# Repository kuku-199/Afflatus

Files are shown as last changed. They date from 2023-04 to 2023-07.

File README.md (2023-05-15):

# Afflatus💡
           
* [**中文版本**](./README_zh.md)
## Afflatus STM32G4xx Open Development Board🚀
* This project used STM32G431 to master chip.A complete board to be made up of **Commaner**+**Expansion**
>`STM32G431CBU6` Core Board

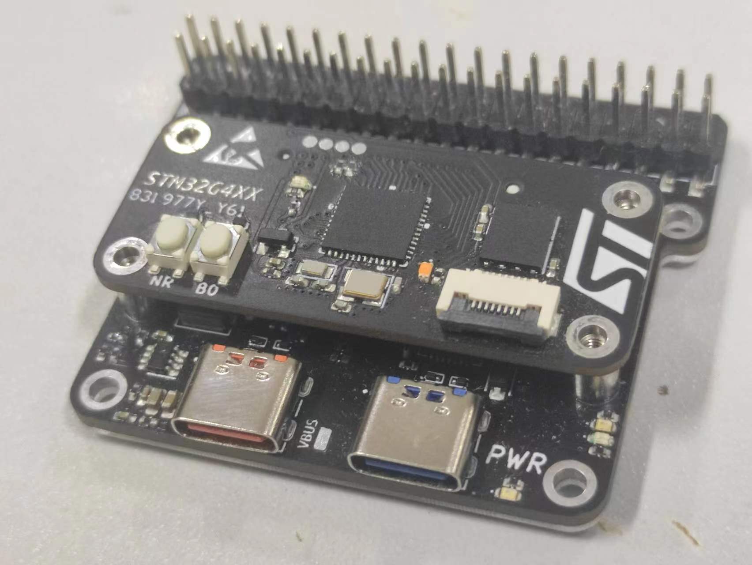
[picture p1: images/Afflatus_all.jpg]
"Afflatus_all"


## Commander✨📟

|Top|Bottom|
|:--:|:--:|
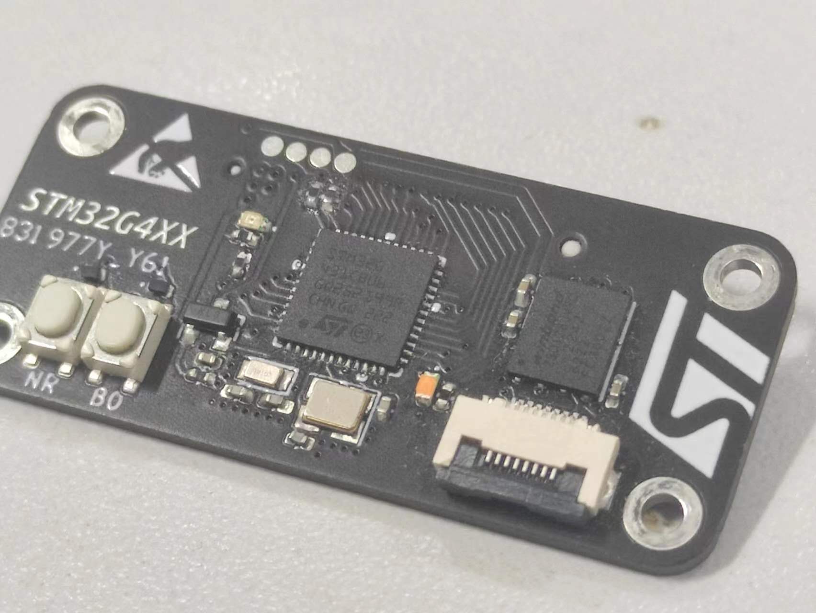
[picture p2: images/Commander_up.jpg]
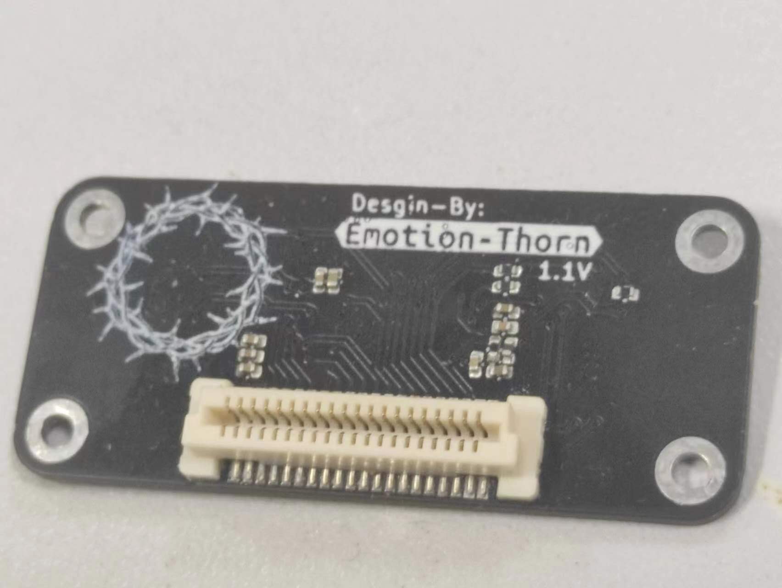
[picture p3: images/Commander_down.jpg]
"down"
||

>At present core boaed onboard Flash,LED,NRST and BOOT0 keys,Reserved serial interface of LDC,Need`0.8mm wire the connection`

>Commander have used `0.8mm`BTB_2x20P，`Not connected to Expansion`Download program can use reserved SW bonding pad to connected `Cable`or`Test probe`Download program

>Commander`none the LDO and DC-DC to buck`,to the extent that core board power only give`3.3V`❗ ❗ ❗

## Expansion🔌⚡🚀

|Top|Bottom|
|:--:|:--:|
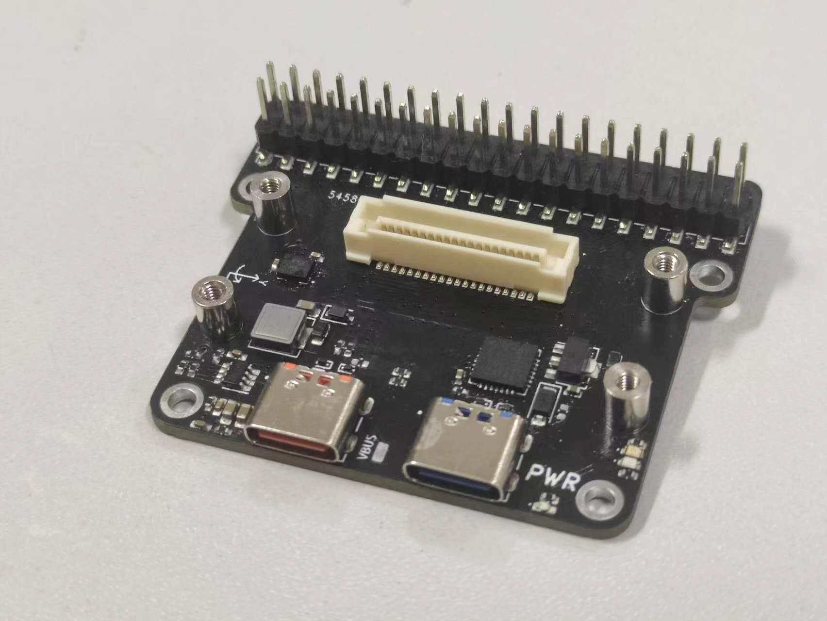
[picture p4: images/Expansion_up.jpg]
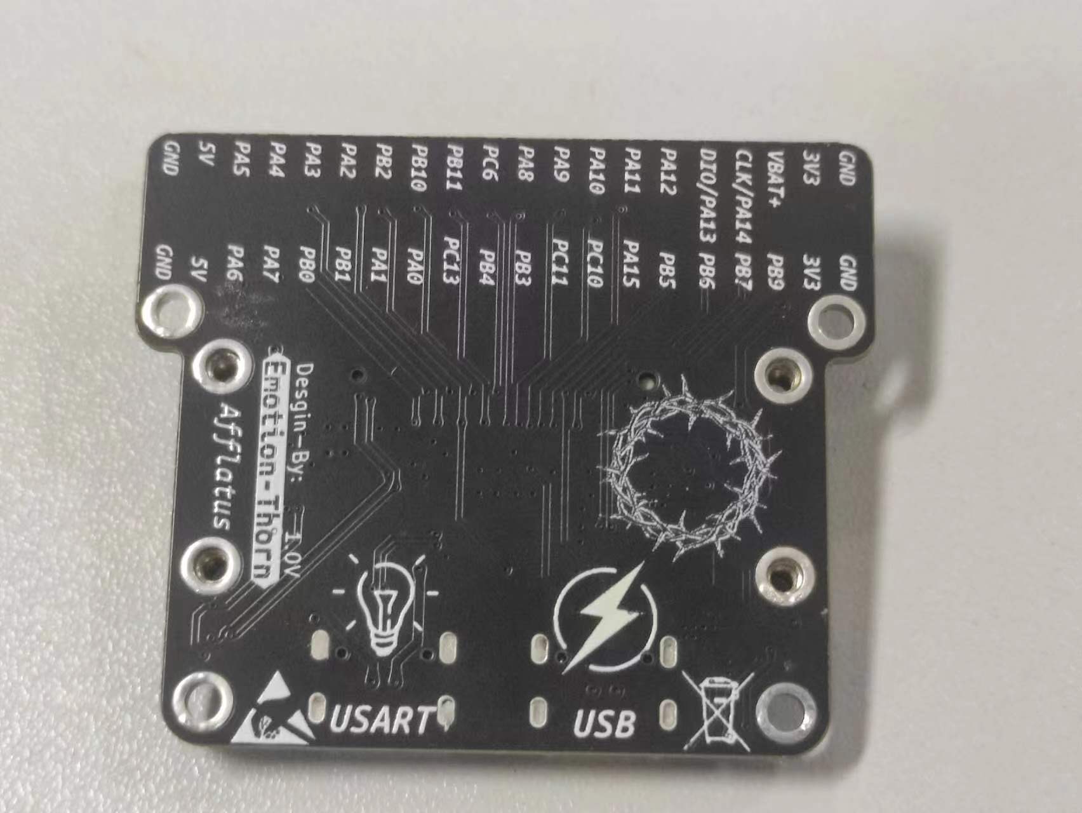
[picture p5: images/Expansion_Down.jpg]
"down"
||

* 1 USB support PD
* 1 USART to USB port
* 1 IMU(BMI270)
* 1 40P header 

>Expansion have one`CP2102`USB can be connected for serial communication.STM32G431CBU6 support `UCPD`so the USB plug support PD and have one DC-DC buck module⚡

>Consider that newbies may be less likely to use the STM32's built-in USB hardware controls,so i reserved USB_D+ pull-up R CC1,CC2 pull-down R`0402`bonding pad,it's recommended to weld pull-down R for CC1 and CC2🔌

>Expansion the type of embedded stud is`M2x4x5.0x2.5x1.0`,BTB combined height is`5.0mm`
I/O Pin header is 2.54mm`SMT`.Optionally add baseplate for Expansion,[**Baseplate file**](./HDK/Expansion/Choice.dxf)effect maps
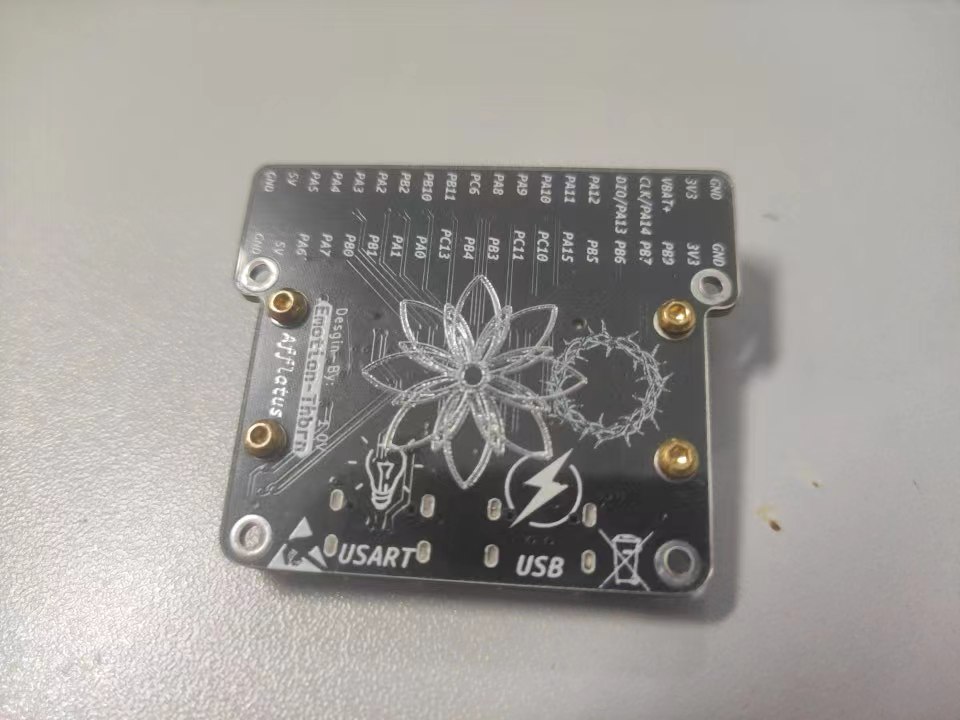
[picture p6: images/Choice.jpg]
"Choice"


## Important statement ❗ ❗ ❗

*  ⚠️Please read the PCB Engineering Instructions pdf file
    - 📖[Engineering declaration](./%E5%B7%A5%E7%A8%8B%E5%A3%B0%E6%98%8E.pdf)
* 👓The whole project uses a two-layer process. If you don't have kicad installed, you can directly view Bom for welding. Gerber files are also in HDK
    - [**Commander-bom**](htmlpreview.github.io/?./HDK/Commander/bom/Commander.html)
    - [**Expansion-bom**](./HDK/Expansion/bom/Expansion.html)
* Continuous update, currently replenishing Demo.📃
* welcome to submit your questions, and I also hope you can submit your own updates to the project📡
* I E-mail**2981263629@qq.com**,if you have questions or new idea can send an email to me⌨
* ❗ ❗ ❗ BUG of IO silk-screen in early stage versions,do not affect usage.(Partial left-right reverse).It has now been repaired.❗ ❗ ❗

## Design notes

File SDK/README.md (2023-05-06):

# Ongoing update📤
## Test file can test flash usart usb imu(bmi270) and led(Suggestion after created Download this program)🎫
## USB file have more example about developement of USB_Deviec.
* ## [**Detailed description(USB)**](./USB/README.md)👈
## Demo file have example for Afflatus DSP and help document
* ## [**Detailed description(Demo)**](./Demo/README.md)👈

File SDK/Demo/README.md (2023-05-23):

# About Demo 
## ADC NOTE:
> In ADC_Demo VBUS value may not be accurate.Becuase this value from resistance divider.In fact, it should be use float when you calculate it ,but this demo i use int.

>If you just put in USART ,there is also voltage in VBUS(about2.7v). 

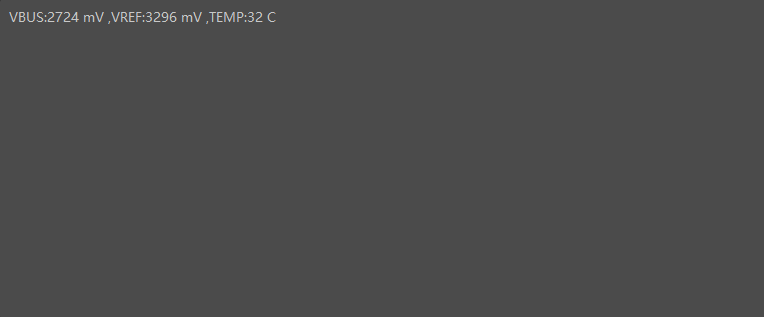
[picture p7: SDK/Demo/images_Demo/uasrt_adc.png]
"USART_ADC"
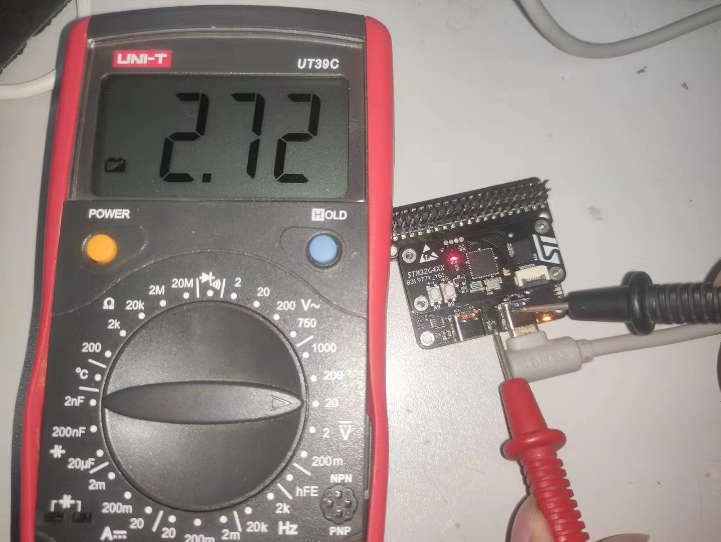
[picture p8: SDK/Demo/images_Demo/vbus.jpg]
"VBUS"
|
## WS2812 NOTE:
>In WS2812 Demo i used WS2812B.If you don't have a light strip, you can get the data in hdk

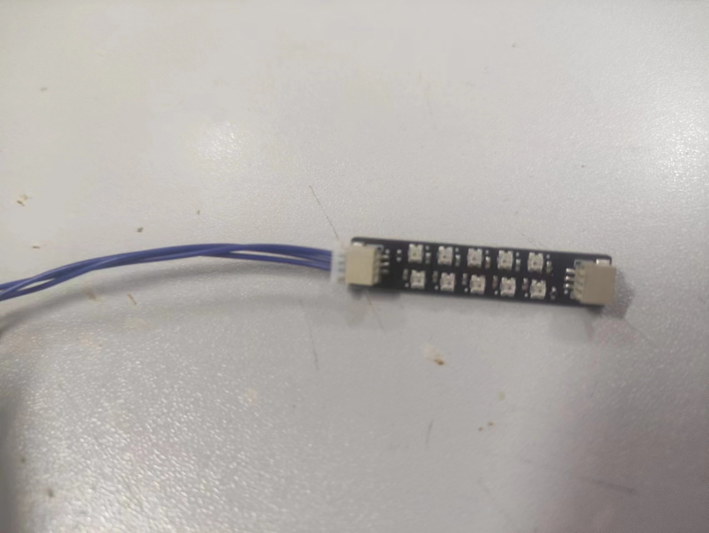
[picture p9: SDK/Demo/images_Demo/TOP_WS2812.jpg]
"TOP"
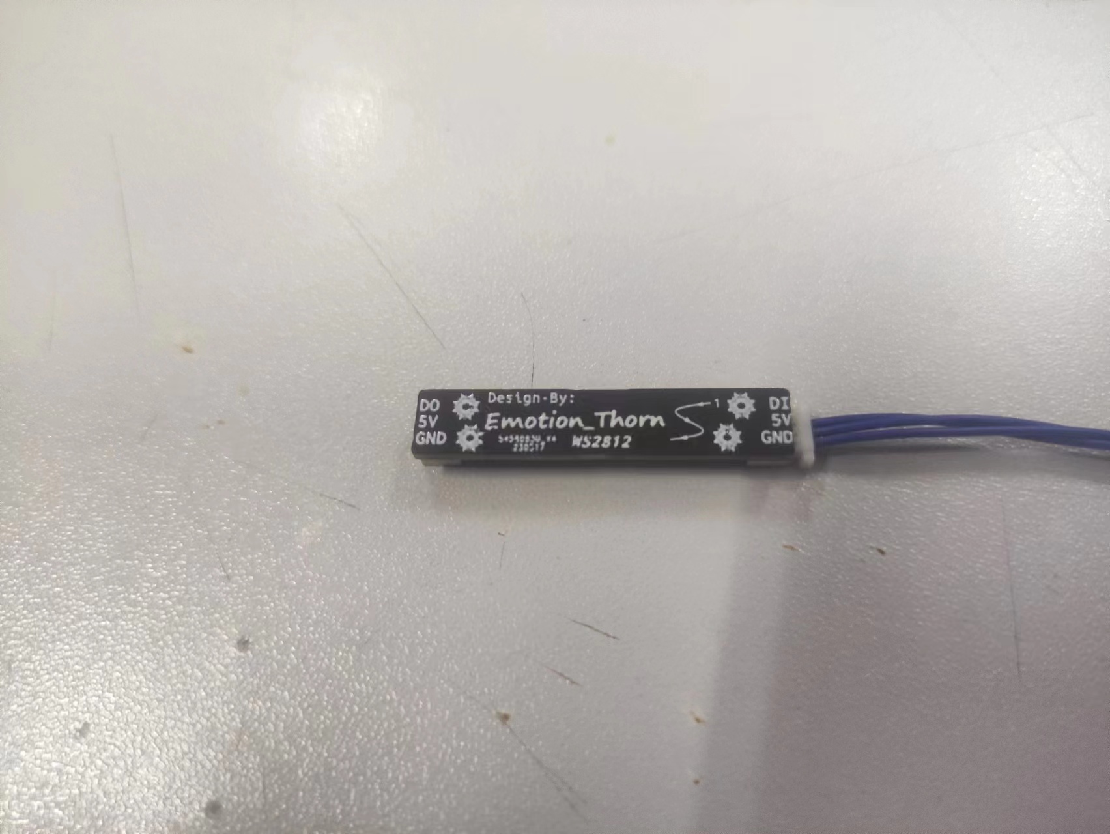
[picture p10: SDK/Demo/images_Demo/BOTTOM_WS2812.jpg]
"BOTTOM"
|
## In this File you use DSP of Afflatus API 
## Support Feature List👇
* Flash(W25Qxx)  [**Help Document**](./Doc/W25Qxx.pdf)👈
* ADC is used STM_HAL
* RGB(WS2812)[**Help Document**](./Doc/W25Qxx.pdf)👈

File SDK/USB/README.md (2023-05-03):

># USB_VPC
>* Download this program,In your SSCOM can see word "USB_VPC_Test"
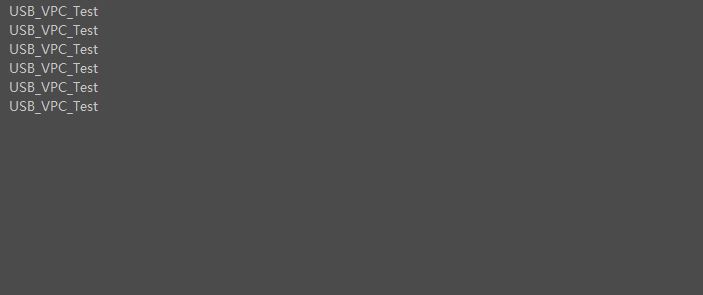
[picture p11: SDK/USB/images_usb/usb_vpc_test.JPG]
"photo_test_word"

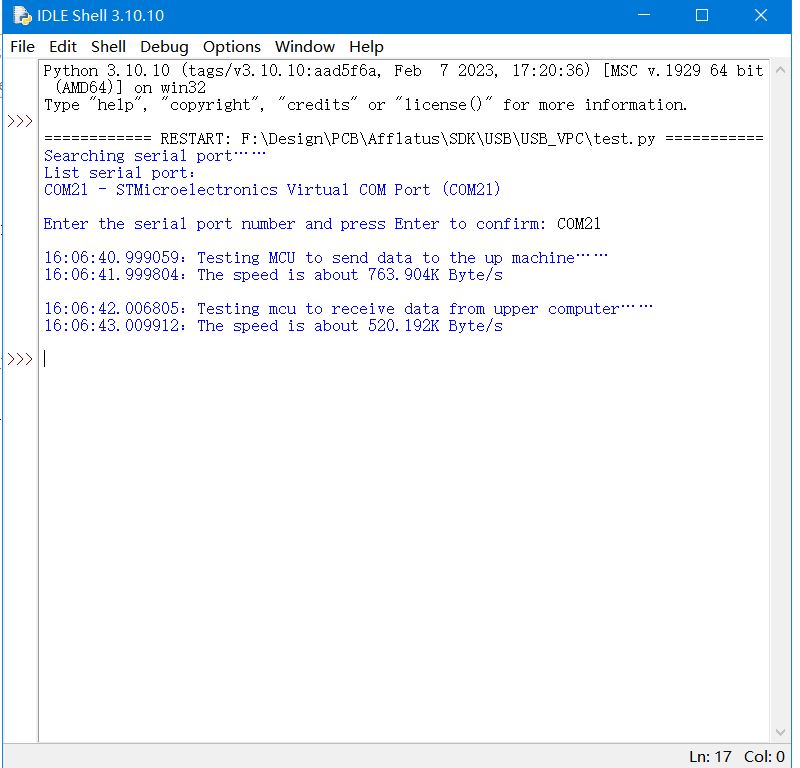
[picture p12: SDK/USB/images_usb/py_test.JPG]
"py_test"
>* If you want to test usb_vpc speed,Use file test.py and input Serial Port Start Test 
>* In this example if you want to use VPC like usart use printf()you need use `usb_printf();`
>* If you want to close usb_vpc speed,in `main.h` find `USB_VPC_SPEED_TEST`

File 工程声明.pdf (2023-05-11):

# 工程声明

编辑日期 2023/04/19 1.
1. 原作者保留对 Afflatus 项目及文件的最终解释的权利。
2. 项目开源协议为 Apache，对原工程进行修改、演绎前提

需阅读 Apache 开源许可 相关权利与义务。

3. 允许商业目的。对于个人或企业团体，使用源工 程或是

演绎版本进 行生产，造成任何质量或功能问题的，与原作者

无关。此条适用上文 第一条最终解释 归属权。

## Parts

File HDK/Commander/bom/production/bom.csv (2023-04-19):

Designator | Footprint | Quantity | Value | LCSC Part #
C1, C3 | 0402 | 2 | 1uF
C10 | 0402 | 1 | 4.7uf
C11, C16, C17, C2, C5, C6, C7, C8, C9 | 0402 | 9 | 100nF
C12, C13, C14, C15 | 0402 | 4 | 15pF
C4 | 0402 | 1 | 10nF
D1 | SOT-23 | 1 | BAT54C
D2, D3 | 0402 | 2 | AZ5725-01F-P
D6 | 0402 | 1 | Purple
D7 | 0402 | 1 | White
FB1 | 0402 | 1 | 1K 100M
J1 | Test_Dot | 1 | SWD
J3 | Hirose_FH12-8S-0.5SH_1x08-1MP_P0.50mm_Horizontal | 1 | FPC0.5-SMT-8
J4 | J | 1 | ~
R1 | 0402 | 1 | 0R
R10, R13 | 0402 | 2 | 1K
R11, R12, R4, R5 | 0402 | 4 | 22R
R14 | 0402 | 1 | 100K
R2, R3 | 0402 | 2 | 10K
SW1 | SW_4P_3x4x2.5mm | 1 | NRST
SW2 | SW_4P_3x4x2.5mm | 1 | BOOT0
U1 | STM32G431CBU6 | 1 | STM32G431CBU6
U3 | WSON-8-1EP_6x5mm_P1.27mm_EP3.4x4mm | 1 | W25Q128JVS
Y1 | Crystal_SMD_3225-4Pin_3.2x2.5mm | 1 | 8M
Y2 | Crystal_SMD_2012-2Pin_2.0x1.2mm_HandSoldering | 1 | 32.768K
j2 | BTB_0.8_2X20P_F | 1 | ~

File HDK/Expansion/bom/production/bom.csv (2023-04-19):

Designator | Footprint | Quantity | Value | LCSC Part #
C1, C10, C6, C7, C9 | 0402 | 5 | 100nF
C13 | 0402 | 1 | 10uF
C14, C2, C3 | 0603 | 3 | 22uF
C4, C5 | 0603 | 2 | 10uF
C8 | 0402 | 1 | 1uF
D1 | D_SOD-323 | 1 | LESD3Z5.0CMT1G
D2, D3, D4, D5 | D_SOD-923 | 4 | ESD9B5.0ST5G
D6 | D_SOD-123 | 1 | 1N5819WS
D7 | 0402 | 1 | Blue
D8 | 0402 | 1 | Yellow
D9 | 0402 | 1 | Yllow
J2 | PinHeader_2x20_P2.54mm_Vertical_SMD | 1 | Conn_02x20_Odd_Even
J3 | SolderWirePad_1x01_SMD_1x2mm | 1 | Conn_01x01_Pin
J4 | Afflatus-outline | 1 | ~
L1 | L_Sunlord_MWSA0402S | 1 | L
R1, R20, R21 | 0402 | 3 | 22R
R10, R11, R12, R9 | 0402 | 4 | 5.1K
R13, R7 | 0402 | 2 | 0R
R14, R15 | 0402 | 2 | 1K
R18 | 0402 | 1 | 200K
R19 | 0402 | 1 | 40.2K
R2, R3 | 0402 | 2 | 100K
R22 | 0402 | 1 | 3.3K
R4 | 0402 | 1 | 51K
R5 | 0402 | 1 | 41.2K
R6 | 0402 | 1 | 13K
R8 | 0402 | 1 | 10K
U1 | TSOT-23-8 | 1 | ~
U2, U3 | Typc-C-16P | 2 | USB_C_16P
U4 | QFN-28-1EP_5x5mm_P0.5mm_EP3.35x3.35mm | 1 | CP2102N-Axx-xQFN28
U5 | XDCR_BMI270 | 1 | BMI270
U6 | SOT-89-3 | 1 | AMS1117
j1 | BTB_0.8_2X20P_M | 1 | ~

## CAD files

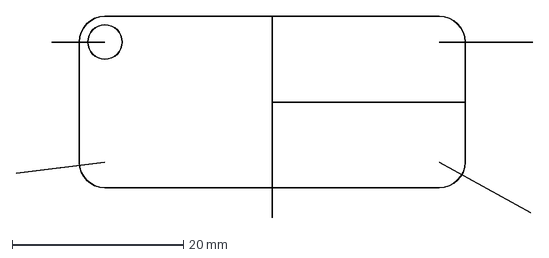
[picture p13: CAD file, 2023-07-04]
HDK/STM32G4/Commander/Outline.dxf
60.3 x 23.5 mm

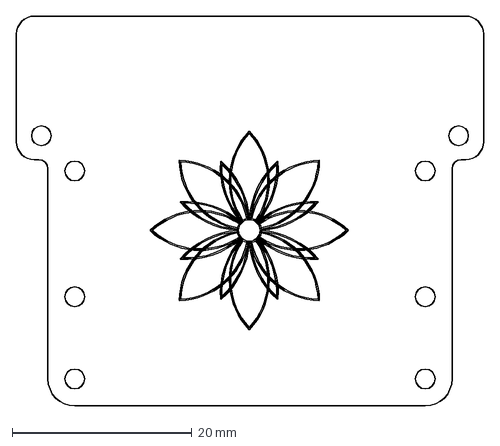
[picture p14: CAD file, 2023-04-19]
HDK/STM32G4/Expansion/Choice.dxf
52.0 x 43.4 mm

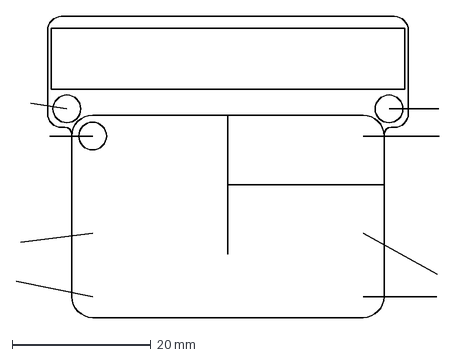
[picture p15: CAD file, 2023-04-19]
HDK/STM32G4/Expansion/Outline.dxf
61.0 x 43.4 mm

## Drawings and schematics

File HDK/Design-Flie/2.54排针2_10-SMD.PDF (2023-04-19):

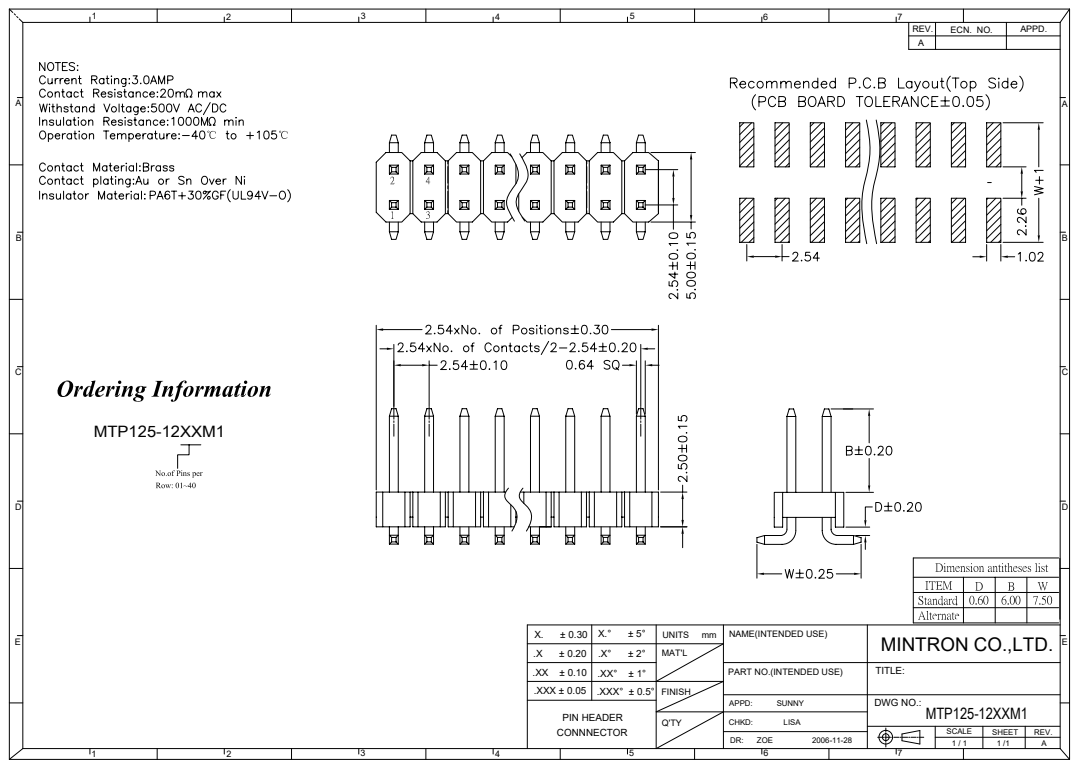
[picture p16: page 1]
PIN HEADER

REV. | ECN. NO. | APPD.

X. ± 0.30 | X.° ± 5° | UNITS mm | NAME(INTENDED USE) | MINTRON CO.,LTD.
.X ± 0.20 | .X° ± 2° | MAT'L
.XX ± 0.10 | .XX° ± 1° | | PART NO.(INTENDED USE) | TITLE:
.XXX ± 0.05 | .XXX° ± 0.5° | FINISH

APPD: SUNNY | DWG NO.: MTP125-12XXM1

Q'TY | CHKD: LISA

SCALE | SHEET | REV.
1 / 1 | 1 /1 | A

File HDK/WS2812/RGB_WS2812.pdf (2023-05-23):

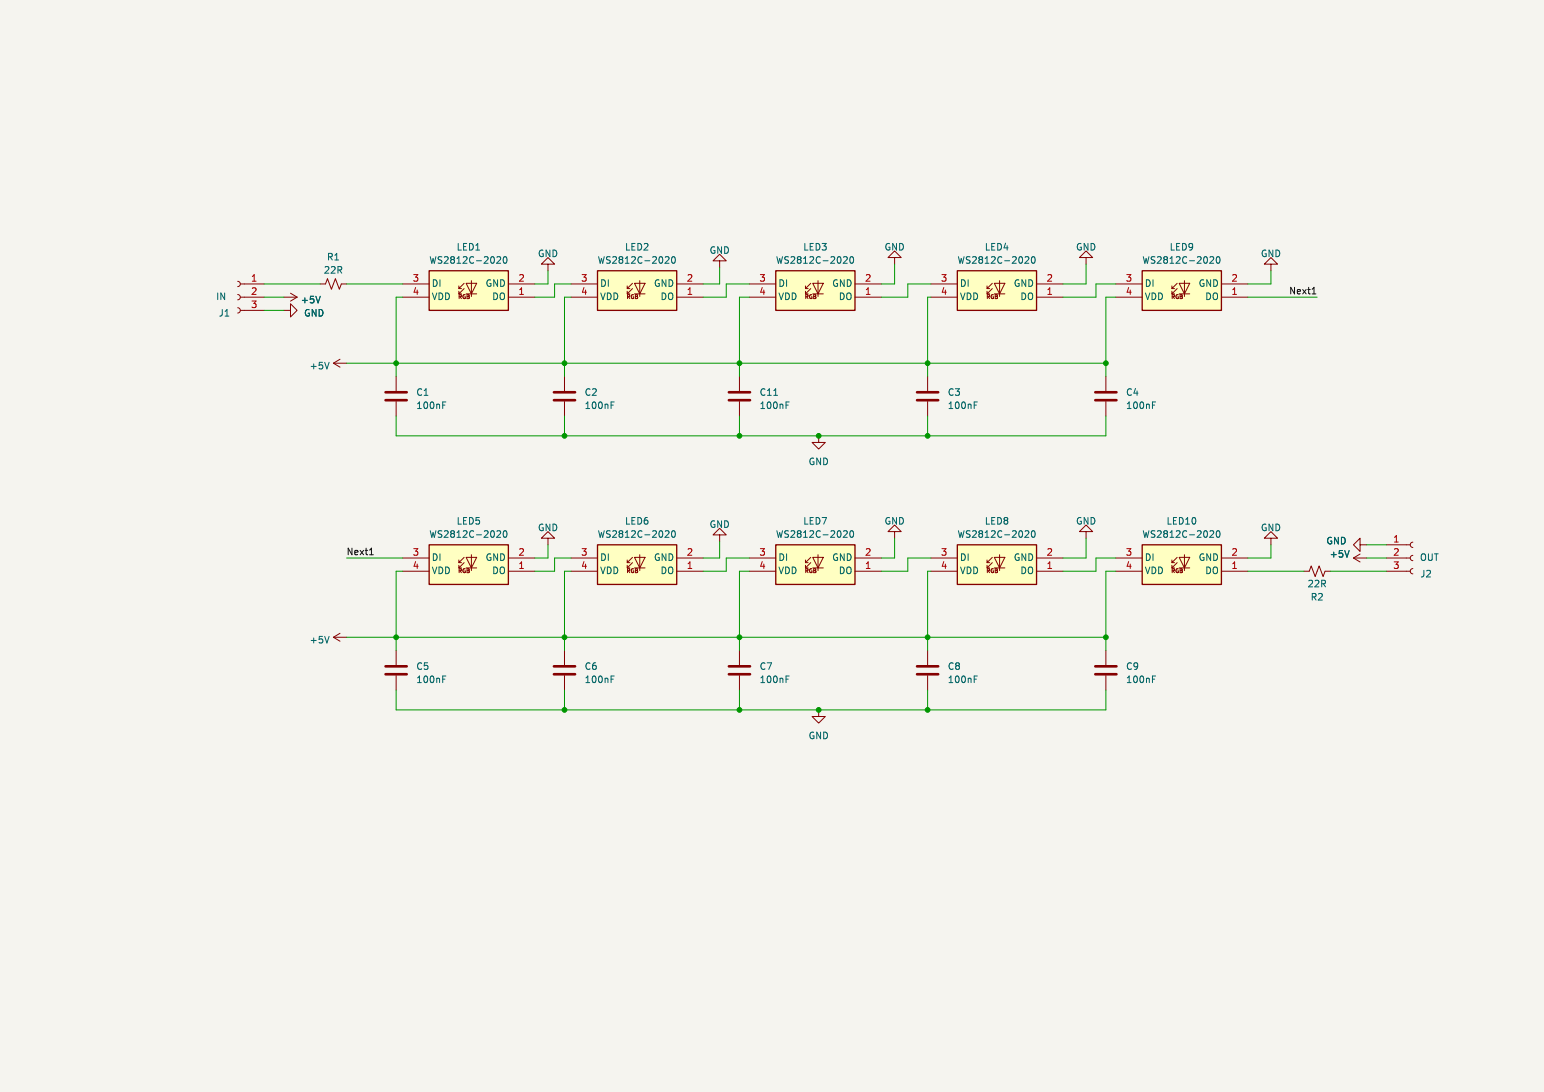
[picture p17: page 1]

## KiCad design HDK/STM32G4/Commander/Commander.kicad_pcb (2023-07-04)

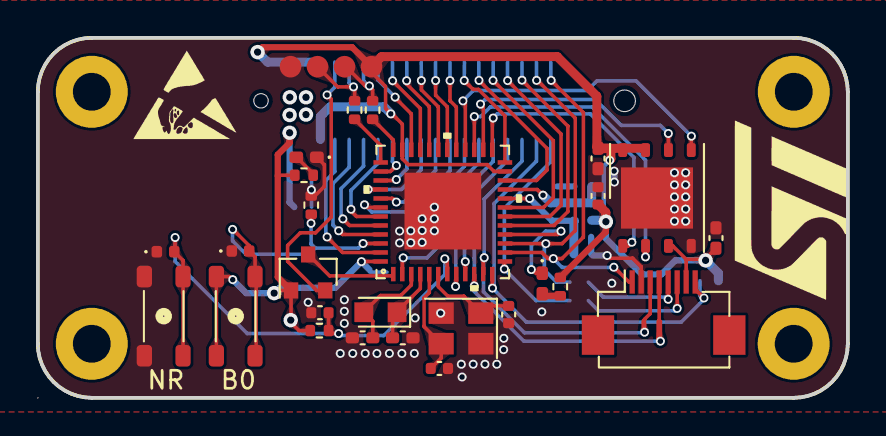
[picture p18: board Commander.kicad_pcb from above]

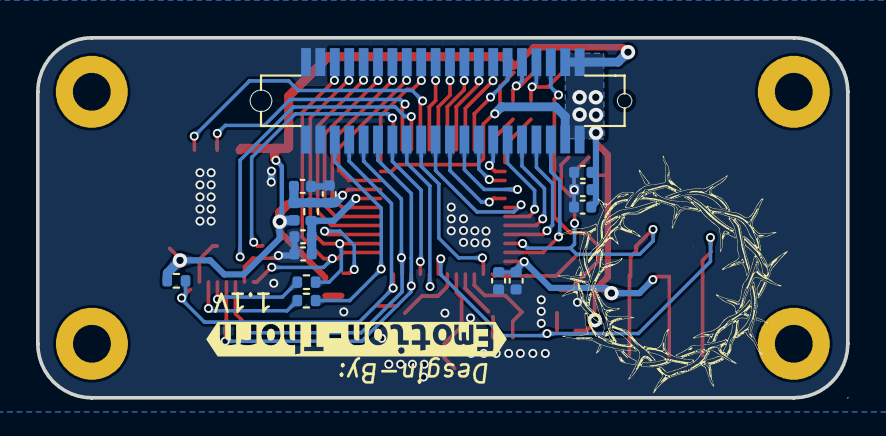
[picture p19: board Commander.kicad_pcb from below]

Board: 2 copper layers, 45.0 x 20.0 mm, 44 parts (16 on the bottom side), 54 nets.

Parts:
C1, C3: 1uF; C_0402_1005Metric
C2, C5, C6, C7, C8, C9, C11: 100nF; C_0402_1005Metric
C4: 10nF; C_0402_1005Metric
C10: 4.7uf; C_0402_1005Metric
C12, C13: 15pF; C_0402_1005Metric
C14, C15: 15pF; C_0402_1005Metric_Pad0.74x0.62mm_HandSolder
C16, C17: 100nF; C_0402_1005Metric_Pad0.74x0.62mm_HandSolder
D1: BAT54C; SOT-23
D2, D3: AZ5725-01F-P; D_0402_1005Metric
D6: Purple; LED_0402_1005Metric_Pad0.77x0.64mm_HandSolder
D7: White; LED_0402_1005Metric_Pad0.77x0.64mm_HandSolder
FB1: 1K 100M; L_0402_1005Metric
J1: SWD; Test_Dot
J3: FPC0.5-SMT-8; Hirose_FH12-8S-0.5SH_1x08-1MP_P0.50mm_Horizontal
J4: J
R1: 0R; R_0402_1005Metric
R2, R3: 10K; R_0402_1005Metric
R4, R5, R11, R12: 22R; R_0402_1005Metric
R10, R13: 1K; R_0402_1005Metric
R14: 100K; R_0402_1005Metric
SW1: NRST; SW_4P_3x4x2.5mm
SW2: BOOT0; SW_4P_3x4x2.5mm
U1: STM32G431CBU6
U3: W25Q128JVS; WSON-8-1EP_6x5mm_P1.27mm_EP3.4x4mm
Y1: 8M; Crystal_SMD_3225-4Pin_3.2x2.5mm
Y2: 32.768K; Crystal_SMD_2012-2Pin_2.0x1.2mm_HandSoldering
j2: BTB_0.8_2X20P_F
kibuzzard-63E5B3C4: G***; kibuzzard-63E5B3C4

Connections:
+3V3: C5.1, C6.1, C7.1, C8.1, C9.1, C10.1, C16.1, C17.1, D1.1, FB1.1, J1.4, J3.7, R2.1, R10.1, R13.1, R14.1, SW2.1, SW2.2, U1.23 (VDD), U1.35 (VDD), U1.48 (VDD), U3.3 (IO2), U3.7 (IO3), U3.8 (VCC), j2.37, j2.38, j2.39, j2.40
/BOOT0: D3.2 (A2), R3.2, SW2.3, SW2.4, U1.46 (PB8-BOOT0)
/LCD.BKControl: J3.1, U1.14 (PA6), j2.6
/LCD.CS: J3.8, R14.2, U1.12 (PA4), j2.7
/LCD.D/C: J3.4, U1.10 (PA2), j2.11
/LCD.SCL: R12.1, U1.13 (PA5), j2.5
/LCD.SDA: R11.1, U1.15 (PA7), j2.8
/LCD.~RES: J3.3, U1.11 (PA3), j2.9
/NRST: C11.1, D2.2 (A2), R2.2, SW1.3, SW1.4, U1.7 (PG10-NRST)
/OSC_32_IN: C14.1, U1.3 (PC14-OSC32_IN), Y2.2
/OSC_32_OUT: C15.1, U1.4 (PC15-OSC32_OUT), Y2.1
/OSC_IN: C12.1, U1.5 (PF0-OSC_IN), Y1.3
/OSC_OUT: C13.1, U1.6 (PF1-OSC_OUT), Y1.1
/PA0: U1.8 (PA0), j2.15
/PA1: U1.9 (PA1), j2.13
/PA8: U1.30 (PA8), j2.22
/PA9: U1.31 (PA9), j2.24
/PA10: U1.32 (PA10), j2.26
/PA11: U1.33 (PA11), j2.28
/PA12: U1.34 (PA12), j2.29
/PA15: U1.38 (PA15), j2.27
/PB0: U1.17 (PB0), j2.10
/PB1: U1.18 (PB1), j2.12
/PB2: U1.19 (PB2), j2.14
/PB3: U1.41 (PB3), j2.21
/PB4: U1.42 (PB4), j2.19
/PB5: U1.43 (PB5), j2.30
/PB6: U1.44 (PB6), j2.32
/PB7: U1.45 (PB7), j2.34
/PB9: U1.47 (PB9), j2.36
/PB10: U1.22 (PB10), j2.16
/PB11: U1.24 (PB11), j2.18
/PC4: D6.1 (K), U1.16 (PC4)
/PC6: U1.29 (PC6), j2.20
/PC10: U1.39 (PC10), j2.25
/PC11: U1.40 (PC11), j2.23
/PC13: U1.2 (PC13), j2.17
/SPI2.CLK: U1.26 (PB13), U3.6 (CLK)
/SPI2.CS: U1.25 (PB12), U3.1 (~CS)
/SPI2.MISO: U1.27 (PB14), U3.2 (DO(IO1))
/SPI2.MOSI: U1.28 (PB15), U3.5 (DI(IO0))
/SWCLK: R5.1, U1.37 (PA14)
/SWCLK-L: J1.2, R5.2, j2.33
/SWDIO: R4.1, U1.36 (PA13)
/SWDIO-L: J1.3, R4.2, j2.31
/VBAT+: D1.3, U1.1 (VBAT)
/VBAT_Pin: D1.2, j2.35
GND: C1.2, C2.2, C3.1, C4.1, C5.2, C6.2, C7.2, C8.2, C9.2, C10.2, C11.2, C12.2, C13.2, C14.2, C15.2, C16.2, C17.2, D2.1 (A1), D3.1 (A1), D7.1 (K), J1.1, J3.2, R3.1, SW1.1, SW1.2, U1.49 (EPAD), U3.4 (GND), Y1.2, Y1.4, j2.1, j2.2, j2.3, j2.4
unnamed: D6.2 (A), R10.2
unnamed: D7.2 (A), R13.2
unnamed: J3.5, R11.2
unnamed: J3.6, R12.2
unnamed: C3.2, C4.2, FB1.2, R1.1, U1.21 (VDDA)
unnamed: C1.1, C2.1, R1.2, U1.20 (VREF+)

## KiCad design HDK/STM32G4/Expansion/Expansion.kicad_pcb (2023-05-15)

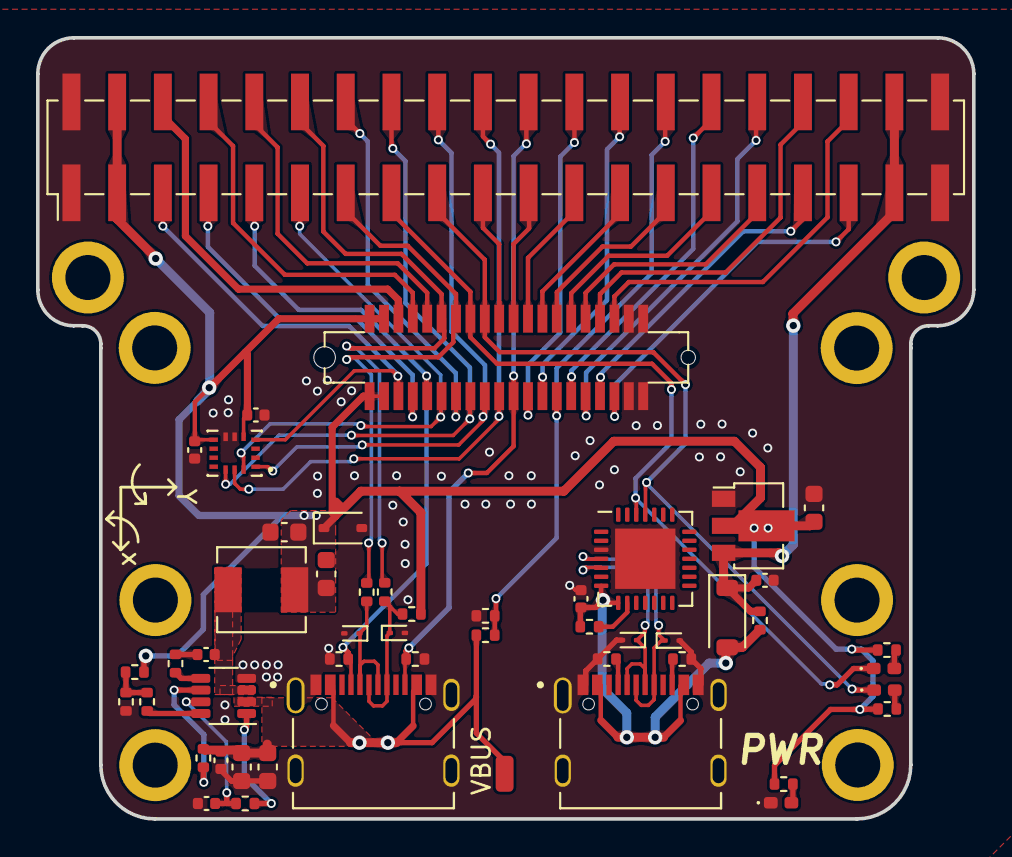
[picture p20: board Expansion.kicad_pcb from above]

Board: 2 copper layers, 52.0 x 43.4 mm, 53 parts (1 on the bottom side), 55 nets.

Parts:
C1, C6, C7, C9, C10: 100nF; C_0402_1005Metric
C2, C3, C14: 22uF; C_0603_1608Metric
C4, C5: 10uF; C_0603_1608Metric
C8: 1uF; C_0402_1005Metric
C13: 10uF; C_0402_1005Metric
D1: LESD3Z5.0CMT1G; D_SOD-323
D2, D3, D4, D5: ESD9B5.0ST5G; D_SOD-923
D6: 1N5819WS; D_SOD-123
D7: Blue; LED_0402_1005Metric_Pad0.77x0.64mm_HandSolder
D8: Yellow; LED_0402_1005Metric_Pad0.77x0.64mm_HandSolder
D9: Yllow; LED_0402_1005Metric_Pad0.77x0.64mm_HandSolder
J2: Conn_02x20_Odd_Even; PinHeader_2x20_P2.54mm_Vertical_SMD
J3: Conn_01x01_Pin; SolderWirePad_1x01_SMD_1x2mm
J4: Afflatus-outline
L1: L; L_Sunlord_MWSA0402S
R1, R20, R21: 22R; R_0402_1005Metric
R2, R3: 100K; R_0402_1005Metric
R4: 51K; R_0402_1005Metric
R5: 41.2K; R_0402_1005Metric
R6: 13K; R_0402_1005Metric
R7, R13: 0R; R_0402_1005Metric
R8: 10K; R_0402_1005Metric
R9, R10, R11, R12: 5.1K; R_0402_1005Metric
R14, R15: 1K; R_0402_1005Metric
R18: 200K; R_0402_1005Metric
R19: 40.2K; R_0402_1005Metric
R22: 3.3K; R_0402_1005Metric
U1: TSOT-23-8
U2, U3: USB_C_16P; Typc-C-16P
U4: CP2102N-Axx-xQFN28; QFN-28-1EP_5x5mm_P0.5mm_EP3.35x3.35mm
U5: BMI270; XDCR_BMI270
U6: AMS1117; SOT-89-3
j1: BTB_0.8_2X20P_M
kibuzzard-63E5B3C4: G***; kibuzzard-63E5B3C4

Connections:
3V3: C2.2, C3.2, C9.2, C10.2, C14.1, D1.1 (A1), J2.3, J2.4, L1.2, R5.2, R7.2, R14.1, R15.1, R22.1, U5.5 (VDDIO), U5.8 (VDD), U6.2 (VO), j1.1, j1.2, j1.3, j1.4
+5V: C13.1, D6.1 (K), J2.37, J2.38, R13.1, U6.3 (VI)
/IMU.BMI270_CLK: J2.20, U5.13 (SCX), j1.19
/IMU.BMI270_CS: J2.16, U5.12 (CSB), j1.15
/IMU.BMI270_EXIT: J2.5, U5.4 (INT1), j1.5
/IMU.BMI270_MISO: J2.18, U5.1 (SDO), j1.17
/IMU.BMI270_MOSI: J2.11, U5.14 (SDX), j1.11
/MCU.USART3_RX: D8.1 (K), J2.17, U4.25 (RXD), j1.18
/MCU.USART3_TX: D7.1 (K), J2.15, U4.26 (TXD), j1.16
/MCU.USB_CC1: J2.9, R11.1, U3.A5 (CC1), j1.9
/MCU.USB_CC2: J2.22, R12.1, U3.B5 (CC2), j1.21
/MCU.USB_DN: D3.1 (A1), R20.1, U3.A7 (D-), U3.B7 (D-)
/MCU.USB_DP: D5.1 (A1), R7.1, R21.1, U3.A6 (D+), U3.B6 (D+)
/PA0: J2.26, j1.25
/PA2: J2.30, j1.30
/PA3: J2.32, j1.32
/PA4: J2.33, j1.34
/PA5: J2.35, j1.36
/PA6: J2.36, j1.35
/PA7: J2.34, j1.33
/PA8: J2.19, j1.20
/PA15: J2.14, j1.13
/PB0: J2.31, j1.31
/PB1: J2.29, j1.29
/PB2: J2.27, j1.28
/PB7: J2.7, j1.7
/PB10: J2.25, j1.26
/PB11: J2.23, j1.24
/PC6: J2.21, j1.22
/PC13: J2.24, j1.23
/SWCLK-L: J2.8, j1.8
/SWDIO-L: J2.10, j1.10
/TYPE-C/USART_USB_CC1: R9.1, U2.A5 (CC1)
/TYPE-C/USART_USB_CC2: R10.1, U2.B5 (CC2)
/TYPE-C/USART_USB_DN: D2.1 (A1), U2.A7 (D-), U2.B7 (D-), U4.5 (D-)
/TYPE-C/USART_USB_DP: D4.1 (A1), U2.A6 (D+), U2.B6 (D+), U4.4 (D+)
/VBAT_Pin: J2.6, j1.6
ADC_VBUS: J2.28, R18.2, R19.1, j1.27
GND: C2.1, C3.1, C4.2, C5.2, C6.2, C7.2, C8.1, C9.1, C10.1, C13.2, C14.2, D1.2 (A2), D2.2 (A2), D3.2 (A2), D4.2 (A2), D5.2 (A2), D9.1 (K), J2.1, J2.2, J2.39, J2.40, R6.2, R9.2, R10.2, R11.2, R12.2, R19.2, U1.4 (GND), U2.A1 (GND), U2.A12 (GND), U2.B1 (GND), U2.B12 (GND), U2.S1 (_), U2.S2 (_), U2.S3 (_), U2.S4 (_), U3.A1 (GND), U3.A12 (GND), U3.B1 (GND), U3.B12 (GND), U3.S1 (_), U3.S2 (_), U3.S3 (_), U3.S4 (_), U4.3 (GND), U4.29 (GND), U5.6 (GNDIO), U5.7 (GND), U6.1 (ADJ), j1.37, j1.38, j1.39, j1.40
unnamed: C1.1, R1.2
unnamed: D7.2 (A), R14.2
unnamed: D8.2 (A), R15.2
unnamed: D9.2 (A), R22.2
unnamed: R4.2, R5.1, R6.1
unnamed: R1.1, U1.5 (BST)
unnamed: R2.2, U1.6 (EN/SYNC)
unnamed: R4.1, U1.8 (FB)
unnamed: R3.1, U1.1 (PG)
unnamed: C1.2, L1.1, U1.3 (SW)
unnamed: C7.1, R3.2, U1.7 (VCC)
unnamed: R8.2, U4.9 (~RST)
USB_DN: J2.13, R20.2, j1.14
USB_DP: J2.12, R21.2, j1.12
VBUS: C8.2, D6.2 (A), R8.1, R13.2, U2.A4 (VBUS), U2.A9 (VBUS), U2.B4 (VBUS), U2.B9 (VBUS), U4.7 (VREGIN), U4.8 (VBUS)
VBUS1: C4.1, C5.1, C6.1, J3.1, R2.1, R18.1, U1.2 (IN), U3.A4 (VBUS), U3.A9 (VBUS), U3.B4 (VBUS), U3.B9 (VBUS)

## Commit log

2023-04-19 Hardware Development Kit
    [Choice.dxf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]
2023-05-15 amend silk-screen
    [Expansion-B_Cu.gbr, Expansion-B_Mask.gbr, Expansion-B_Paste.gbr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]
2023-07-04 Update Commander
    [Commander.kicad_pcb, Commander.kicad_sch, Outline.DXF]
2025-01-30 Add STM32G4XX for Afflatus
    [Choice.dxf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]

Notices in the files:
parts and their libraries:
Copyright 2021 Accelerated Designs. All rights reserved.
